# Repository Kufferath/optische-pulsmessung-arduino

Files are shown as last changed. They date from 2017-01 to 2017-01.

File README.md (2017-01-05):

# optische-pulsmessung-arduino
Optische Pulsmessung mit Arduino und Ausgabe via Nextion Display

In diesem Projekt wir beschrieben , wie man mit Hilfe einer Infrarot-Led und einer Photodiode auf optischem Wege eine Pulsmessung durchführen kann.
Als Basis dient ein Arduino UNO und die Ausgabe erfolgt mit einem Nextion Display.
Als Hardware ist ein Messvertärker erforderlich, der eine Bandpassfunktion aufweist.
Schaltplan und weitere Infos sind hier hinterlegt.

Zum Nachbau des Projekts sind folgende Schritte nötig:

 - Aufbau des Messverstärkers
 - Montage der LED und der Photodiode
 - Programmierung des  Arduino UNO
 - Gestaltung des Layouts für das Nextion Display
 - Verdrahten der Komponenten

Sie finden die nötigen Dateien im Verzeichnis

##Hinweis

>Von besonderem Interesse mag die Einbindung des
>Nextion Displays sein, da es über Serielle Befehle
>zu steuern ist und den Prozessor zur Laufzeit nicht 
>belastet.
>Mit Hilfe des Desktop-Editors von Nextion , ist eine
>einfache Gestaltung des Layouts möglich.

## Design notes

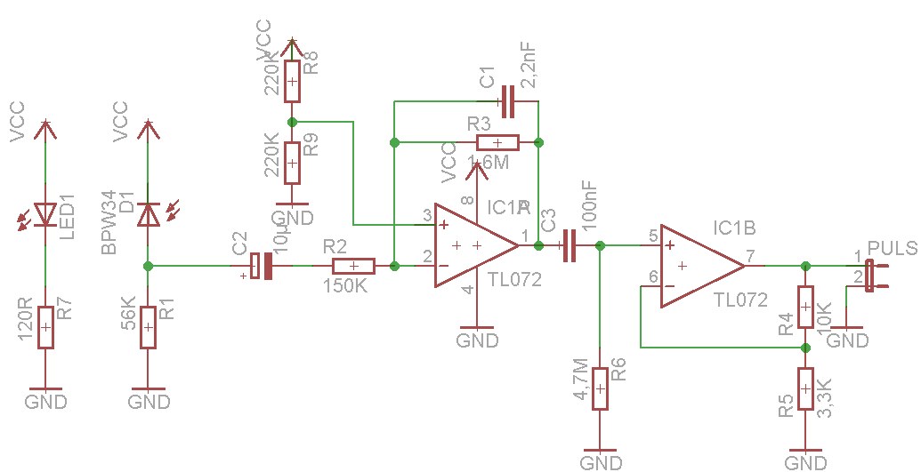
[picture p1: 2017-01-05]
Schaltbild_messverstaerker_Pulsmessung.jpg

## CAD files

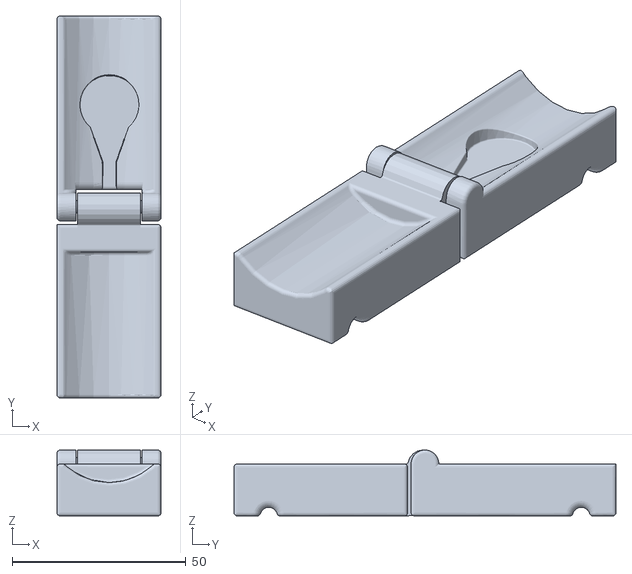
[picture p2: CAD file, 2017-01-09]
pulsoxymeter-final.stl
30.0 x 110.0 x 19.0

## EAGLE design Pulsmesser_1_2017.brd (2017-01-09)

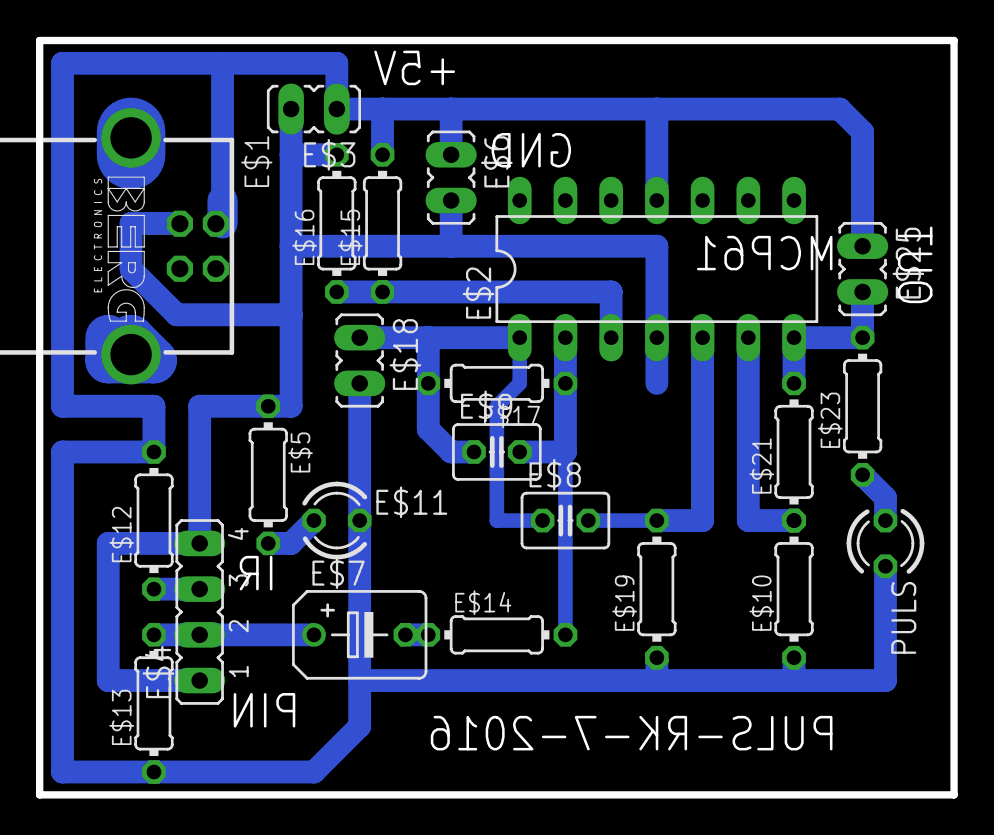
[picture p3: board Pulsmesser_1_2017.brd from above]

Board: 2 copper layers, 50.8 x 41.9 mm, 23 parts (0 on the bottom side), 13 nets.

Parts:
E$1: PN61729-S
E$2: MCP6144; DIL14
E$3, E$6, E$18, E$25: JP1Y
E$4: JP4
E$5: 470R; 0204/7
E$7: B45181B
E$8: C025-030X050
E$9: 2,2nF; C025-030X050
E$10: 2K2; 0204/7
E$11: LED3MM
E$12: 120R; 0204/7
E$13: 50K; 0204/7
E$14: 150K; 0204/7
E$15, E$16: 220K; 0204/7
E$17: 3,3M; 0204/7
E$19: 4,7M; 0204/7
E$21: 10K; 0204/7
E$23: 220R; 0204/7
PULS: LED3MM

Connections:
S$1: E$2.3, E$16.1
S$2: E$2.4, E$3.2, E$4.1, E$4.4, E$6.2, E$16.2
S$3: E$4.3, E$12.1
S$4: E$4.2, E$7.+, E$13.2
S$6: E$7.-, E$14.1
S$7: E$2.2, E$9.2, E$14.2
S$10: E$2.1, E$8.1, E$9.1, E$17.2, E$18.1
S$11: E$2.5, E$8.2
S$13: E$2.6, E$21.1
S$14: E$2.7, E$21.2, E$23.2, E$25.2
S$16: E$23.1, PULS.A
S$18: E$2.11, E$3.1, E$6.1, E$10.1, E$12.2, E$13.1, E$15.2, E$18.2, E$19.1, E$25.1, PULS.K
S$19: E$5.2, E$11.A

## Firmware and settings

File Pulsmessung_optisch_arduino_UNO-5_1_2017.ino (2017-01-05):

/* Pulsmessung_ die erste 2.te
R.Kufferath  Jan - 2017 f
mit AD-max find   */

#include <SoftwareSerial.h>
#include <Nextion.h>
#include <Average.h>

Average<int> ave(5);  // für Mittelwertbildung gleitend
Average<int> wandler(100);

SoftwareSerial nextion(2, 3);// Nextion TX to pin 2 and RX to pin 3 of Arduino

Nextion myNextion(nextion, 9600); //create a Nextion object serial port @ 9600bps

boolean button1State;
boolean button2State;

int old_sensor_value = 0;
  int sensor = 0;
  int value;
  int Puls;
  int Abstand;
  long timer=0;
int state=0;
long grenze=300;  //Schwelle des AD Wertes für Pulserkennung-  Startwert- wird später angepasst;
  
void setup() {
  Serial.begin(9600);
  myNextion.init();
    pinMode(A0,INPUT);
            }

void loop() {
  int maxat = 0;
  String message = myNextion.listen();

 if(message != ""){ // if a message is received...
Serial.println(message);} //...print it out

  if (message == "65 0 1 0 ffff ffff ffff") {
    myNextion.buttonToggle(button1State, "b0", 0, 2);
    Serial.println("B0 - ");
  }
  if (message == "65 0 2 0 ffff ffff ffff") {
    myNextion.buttonToggle(button2State, "b1", 0, 2);
    Serial.println("B1 - ");
  }
//**************** Messung Puls ***********************
value = analogRead(A0);
//Serial.println(value);
sensor = value;
wandler.push(value);  // Mittelwert des AD Wandlerwertes, MAx/MIN ermitteln...

grenze=wandler.maximum(&maxat)*8/10;  //Anpassen der Erkennungsschwelle auf 80%

 if (value>grenze&& grenze>200) {
    // falls aktiver Zustand 0
    if (state==0) {
      // zu Zustand 1 Übergehen
      state=1;
      // Zeit merken
      timer=millis();
    }
    
    // falls aktiver Zustand 2
    if (state==2) {
      
      // zu Startzustand zurÃ¼ckkehren
      state=0;
      // Zeitdifferenz berechnen
      long ms=millis()-timer;
      // Puls berechnen und ausgeben
      if (ms>400) {
        //Serial.print("Puls (1/min): ");
        Puls= 60000/ms; // Puls berechnet
        Serial.print(Puls);
         Serial.print("  ");
        ave.push(Puls); //Aktuellen Puls in die Mittelwertbildung...
        //Serial.print("Puls (mean): ");
        Puls= 60000/ms; // Puls berechnet
        Serial.println(ave.mean());
        Serial.print("MaxAD:"); Serial.println(wandler.maximum(&maxat));
        Serial.println(grenze);
      }
    }
  }
  if (value<300 && state==1) {
    // zu Zustand 2 Ã¼bergehen
    state=2;
  }
//*************************************************************

  if (abs(sensor - old_sensor_value) > 20) { //Nur Updaten wenn eine Differenz größerer 2 ist
    old_sensor_value = sensor;

    int scaled_value = map(sensor, 0, 1023, 0, 100); // always map value from 0 to 100

     myNextion.setComponentValue("j0", scaled_value);  //Progressbar setzen
     
      myNextion.setComponentText("t0", String(ave.mean(),0 ));  // Ausgabe Puls an t0
     
     if (ave.mean()>60 && ave.mean()<120)  {
       myNextion.setComponentText("t6", "98");  // Oxygen
      myNextion.setComponentText("t1", "Ruhe :)"); } // Ruhe
      else  myNextion.setComponentText("t1", " - - - ");
        if (ave.mean()>120)  {
      myNextion.setComponentText("t1", "Stress !");  // Stress
       myNextion.setComponentText("t6", "97");  // Oxyen
       }
   
    
  }
}
